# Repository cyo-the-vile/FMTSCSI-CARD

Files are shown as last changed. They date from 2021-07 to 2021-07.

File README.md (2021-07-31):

# FMTSCSI-CARD
PCB to use an internal SCSI device such as a hard drive.

I will warn you this is absolutely untested but I'm confident it should work.
Connector is based on Labo-san's research for SCSI devices and it looks like it matches my hard drive tray for my FMT FRESH.

The connectors for SCSI and FMT must be right angle connectors. 

Connectors must be 2.54mm pitch, right angle, 50 pin, 2 row.

One connector you can use for FMT side is part number: 30350-5002HB

One connector you can use for SCSI side is part number: 66527-025LF

However there are other parts you can use that could be cheaper and available.

The voltage receptables are labeled if you wanted to use a mechanical hard drive.  I would expect in 2021, everyone uses hard drive emulators.

Please contact me on twitter if there is any questions or trouble  @cyothevile

To get PCB created, take the V1 Card.zip to a factory.

＃FMTSCSI-CARD
ハードドライブなどの内蔵SCSIデバイスを使用するPCB。

日本人の友達、これは機械翻訳です。ご不明な点がございましたらご連絡ください。私のツイッターアカウント：cyothevile。

これは完全にテストされていないことを警告しますが、動作するはずです。
コネクタは、LaboさんのSCSIデバイスの調査に基づいており、FMTFRESHのハードドライブトレイと一致しているようです。

SCSIおよびFMTのコネクタは、直角コネクタである必要があります。

コネクタは、2.54mmピッチ、直角、50ピン、2列である必要があります。

FMT側に使用できるコネクタの1つは、部品番号：30350-5002HBです。

SCSI側に使用できるコネクタの1つは、部品番号：66527-025LFです。

ただし、他にも安価で入手可能な部品があります。

機械式ハードドライブを使用する場合は、許容電圧にラベルが付けられています。 2021年には、誰もがハードドライブエミュレーターを使用すると思います。

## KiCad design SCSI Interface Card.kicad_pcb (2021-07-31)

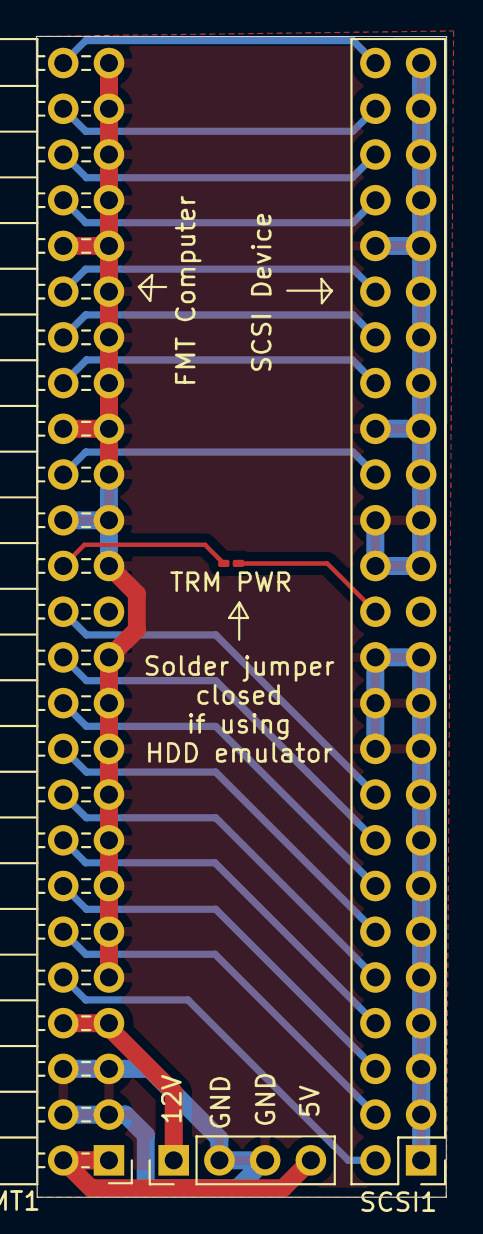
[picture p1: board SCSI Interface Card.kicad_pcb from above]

Board: 2 copper layers, 22.8 x 64.5 mm, 4 parts (0 on the bottom side), 22 nets.

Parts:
FMT1: Conn_02x25_Odd_Even; PinHeader_2x25_P2.54mm_Horizontal
PWR1: Conn_01x04; PinHeader_1x04_P2.54mm_Vertical
SCSI1: Conn_02x25_Odd_Even; PinHeader_2x25_P2.54mm_Vertical
TRM PWR: Conn_01x02_Male; C_0201_0603Metric_Pad0.64x0.40mm_HandSolder

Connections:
/5V: FMT1.1, FMT1.2, PWR1.4
/12V: FMT1.7, FMT1.8, PWR1.1
/ACK: FMT1.38, SCSI1.38
/ATN: FMT1.32, SCSI1.32
/BSY: FMT1.36, SCSI1.36
/CD: FMT1.46, SCSI1.46
/DB0: FMT1.10, SCSI1.2
/DB1: FMT1.12, SCSI1.4
/DB2: FMT1.14, SCSI1.6
/DB3: FMT1.16, SCSI1.8
/DB4: FMT1.18, SCSI1.10
/DB5: FMT1.20, SCSI1.12
/DB6: FMT1.22, SCSI1.14
/DB7: FMT1.24, SCSI1.16
/DBP: FMT1.26, SCSI1.18
/IO: FMT1.50, SCSI1.50
/REQ: FMT1.48, SCSI1.48
/RST: FMT1.40, SCSI1.40
/SEL: FMT1.44, SCSI1.44
/TRM_1: SCSI1.26, TRM PWR.1
/TRM_2: FMT1.28, TRM PWR.2
GND: FMT1.3, FMT1.4, FMT1.5, FMT1.6, FMT1.9, FMT1.11, FMT1.13, FMT1.15, FMT1.17, FMT1.19, FMT1.21, FMT1.23, FMT1.27, FMT1.29, FMT1.30, FMT1.31, FMT1.33, FMT1.34, FMT1.35, FMT1.37, FMT1.39, FMT1.41, FMT1.42, FMT1.43, FMT1.45, FMT1.47, FMT1.49, PWR1.2, PWR1.3, SCSI1.1, SCSI1.3, SCSI1.5, SCSI1.7, SCSI1.9, SCSI1.11, SCSI1.13, SCSI1.15, SCSI1.17, SCSI1.19, SCSI1.20, SCSI1.21, SCSI1.22, SCSI1.23, SCSI1.24, SCSI1.27, SCSI1.28, SCSI1.29, SCSI1.30, SCSI1.31, SCSI1.33, SCSI1.34, SCSI1.35, SCSI1.37, SCSI1.39, SCSI1.41, SCSI1.42, SCSI1.43, SCSI1.45, SCSI1.47, SCSI1.49
